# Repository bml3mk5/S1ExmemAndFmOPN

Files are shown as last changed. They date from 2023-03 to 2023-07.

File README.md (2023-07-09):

# Extended RAM & FM Synthesis Card for HITACHI MB-S1

This is the extension card for HITACHI MB-S1 and Limelight. This is assembled two circuits
which are extended RAMs and FM Synthesis (YAMAHA YM2203(OPN)). You can use two circuits, or just one of them.

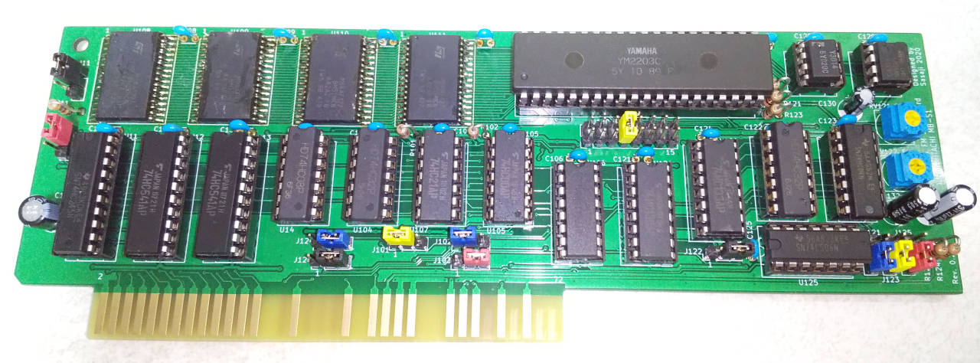
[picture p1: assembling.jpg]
Example of an assembling


## Used Tools

* KiCAD Version 5

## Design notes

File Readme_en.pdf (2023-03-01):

## Extended RAM & FM Synthesis Card for HITACHI MB-S1

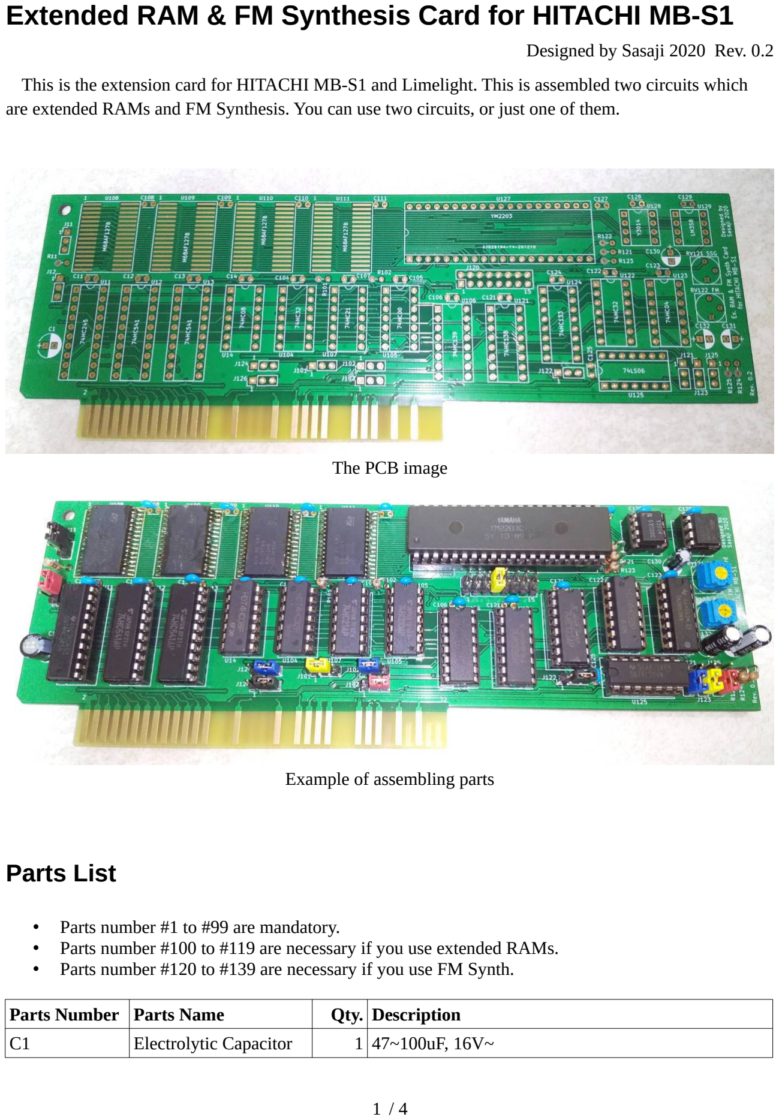
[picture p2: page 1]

Designed by Sasaji 2020 Rev. 0.2 This is the extension card for HITACHI MB-S1 and Limelight. This is assembled two circuits which are extended RAMs and FM Synthesis. You can use two circuits, or just one of them.

The PCB image

Example of assembling parts

## Parts List

- Parts number #1 to #99 are mandatory.
- Parts number #100 to #119 are necessary if you use extended RAMs.
- Parts number #120 to #139 are necessary if you use FM Synth.
Parts Number | Parts Name | Qty. | Description
C1 | Electrolytic Capacitor | 1 | 47~100uF, 16V~

C11~C129 | Ceramic Capacitor | 20 | 0.1uF
C130 | Electrolytic Capacitor | 1 | 10uF, 16V~
C131,C132 | Electrolytic Capacitor | 2 | 22uF~47uF, 16V~
R11~R102 | Carbon Resistor | 3 | 4.7KΩ~10KΩ, 1/4W~
R121~R125 | Carbon Resistor | 5 | 1KΩ, 1/4W～
RV121 | Potentiometer | 1 | 2KΩ Ex: Tokyo Cosmos GF063P1B202
RV122 | Potentiometer | 1 | 10KΩ Ex: Tokyo Cosmos GF063P1B103
U11 | CMOS Logic IC | 1 | 74HC245, DIP20
U12, U13 | CMOS Logic IC | 2 | 74HC541, DIP20
U14 | CMOS Logic IC | 1 | 74HC08, DIP14
U104,U122 | CMOS Logic IC | 2 | 74HC32, DIP14
U105 | CMOS Logic IC | 1 | 74HC00, DIP14
U106 | CMOS Logic IC | 1 | 74HC139, DIP16
U107 | CMOS Logic IC | 1 | 74HC21, DIP14
U108~U111 | SRAM | 4 | STMicro M68AF127B or compatible SRAM(618128), SOIC32
U121 | CMOS Logic IC | 1 | 74HC138, DIP16
U123 | CMOS Logic IC | 1 | 74HC04, DIP14
U124 | CMOS Logic IC | 1 | 74HC133, DIP16
U125 | TTLLogic IC | 1 | 74LS06, DIP14
U127 | FM Synth IC | 1 | YM2203, DIP40
U128 | DAC | 1 | Y3014, DIP8
U129 | Opamp | 1 | LM358 or LM2904, DIP8
J11~J126 | Jumper | 11 | Pin Header 3pin x1 2.54mm pitch
J120 | Jumper | 1 | Pin Header 8pin x2 2.54mm pitch
| Jumper pin | 12 | To short pin headers.
| ICsocket | | If need.

## Setting Jumper

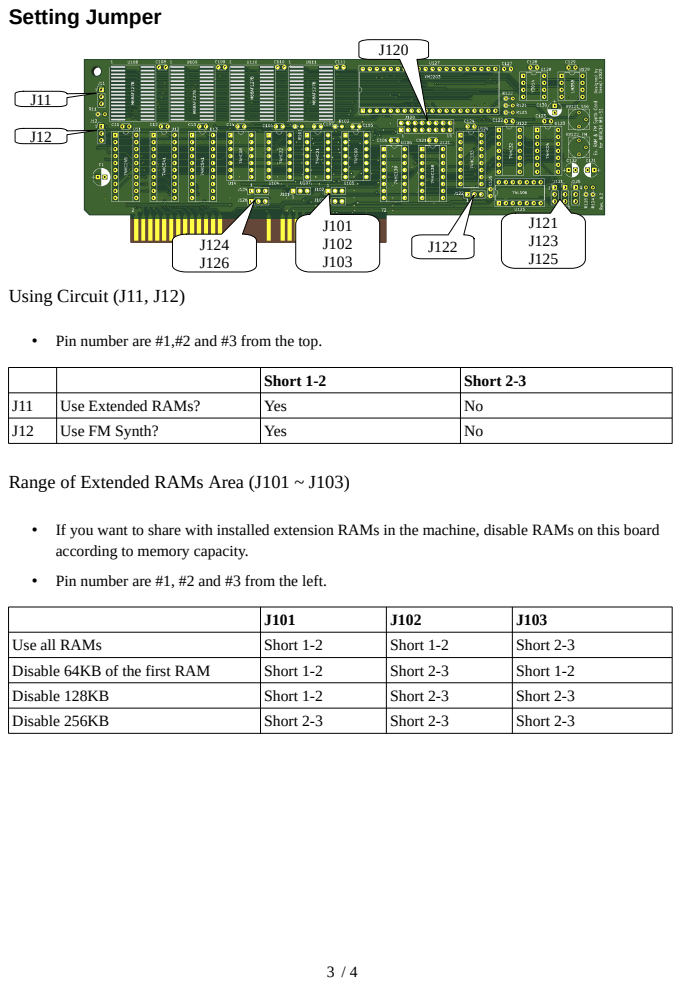
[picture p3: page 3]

• Pin number are #1,#2 and #3 from the top.

Short 1-2 | Short 2-3

J11 | Use Extended RAMs? | Yes | No
J12 | Use FM Synth? | Yes | No

Range of Extended RAMs Area (J101 ~ J103)

• If you want to share with installed extension RAMs in the machine, disable RAMs on this board
according to memory capacity.
• Pin number are #1, #2 and #3 from the left.

Use all RAMs | Short 1-2 | Short 1-2 | Short 2-3
Disable 64KB of the first RAM | Short 1-2 | Short 2-3 | Short 1-2
Disable 128KB | Short 1-2 | Short 2-3 | Short 2-3
Disable 256KB | Short 2-3 | Short 2-3 | Short 2-3

I/O Addresses of FM Synth (J120 ~ J125)

- Pin number #1 of J120 is the bottom left, #2 is the top left, and #16 is the top right. Short top pins and bottom pins.
- Pin number of J121, J123 and J125 are #1, #2 and #3 from the top.
- Pin number of J122 and J124 are #1, #2 and #3 from the left.
| J120 | J121 ~ J125
Use I/O Addresses at $FF1E and $FF1F | Short 15-16 | Short 1-2
Use I/O Addresses at $FFE6 and $FFE7 (*1) | Short 7-8 | Short 2-3

(*1) Select this if you use as Extended PSG.

Connecting Interrupt Signal of FM Synth (J126)

- Pin number are #1, #2 and #3 from the left.
| | Short 1-2 | Short 2-3
J126 | Connect to | IRQ | FIRQ

## Attention

- Make sure to short the jumper J120 only in one place. If you short-circuit multiple places, the IC will be destroyed.
- This board is a prototype. No consideration is given to noise generated during use and deterioration over time.

## Disclaimer

I am not responsible for any damage caused by this board. You use this board at your own risk.

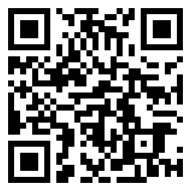
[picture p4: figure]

## Web

http://s-sasaji.ddo.jp/bml3mk5/s1exmemfm.htm QR Code --->

Sasaji (sasaji@s-sasaji.ddo.jp) http://s-sasaji.ddo.jp/bml3mk5/
(Twitter: https://twitter.com/bml3mk5)

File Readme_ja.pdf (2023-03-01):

## 拡張 RAM & FM 音源カード for 日立 MB-S1

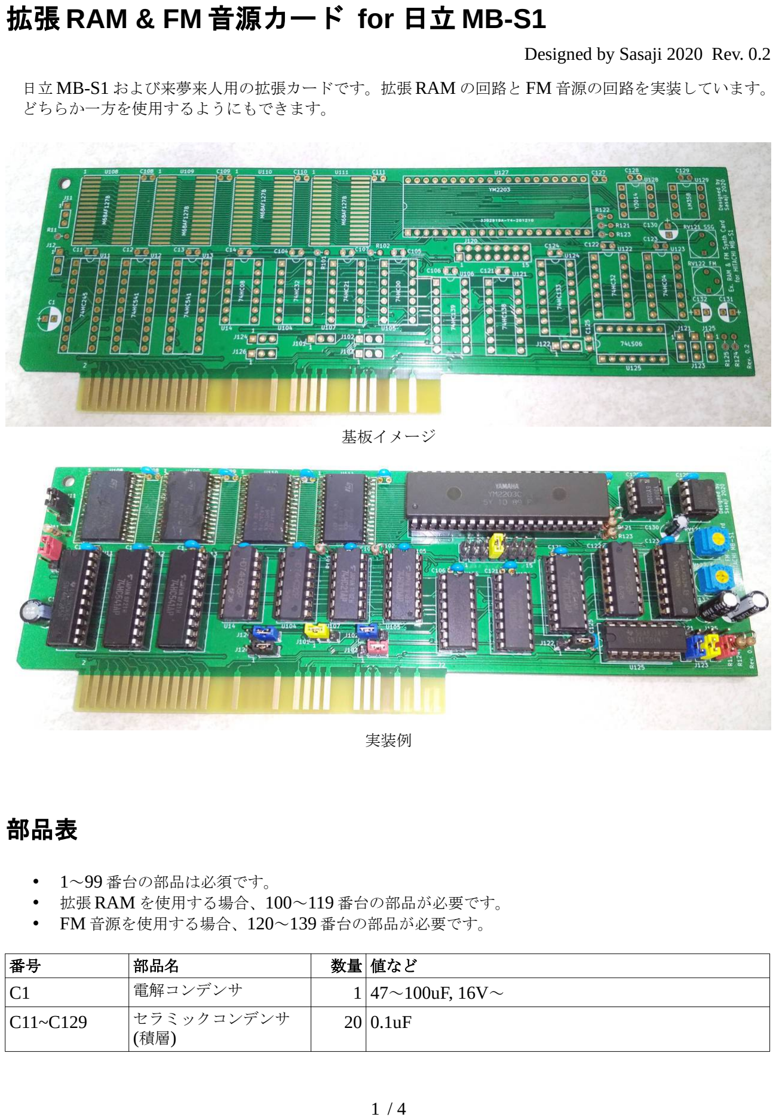
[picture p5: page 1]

Designed by Sasaji 2020 Rev. 0.2

日立 MB-S1 および来夢来人用の拡張カードです。拡張 RAM の回路と FM 音源の回路を実装しています。 どちらか一方を使用するようにもできます。

基板イメージ

実装例

### 部品表

- 1～99 番台の部品は必須です。
- 拡張 RAM を使用する場合、100～119 番台の部品が必要です。
- FM 音源を使用する場合、120～139 番台の部品が必要です。
番号 | 部品名 | 数量 | 値など
C1 | 電解コンデンサ | 1 | 47～100uF, 16V～
C11~C129 | セラミックコンデンサ (積層) | 20 | 0.1uF

C130 | 電解コンデンサ | 1 | 10uF, 16V～
C131,C132 | 電解コンデンサ | 2 | 22uF～47uF, 16V～
R11~R102 | カーボン抵抗 | 3 | 4.7KΩ～10KΩ, 1/4W～
R121~R125 | カーボン抵抗 | 5 | 1KΩ, 1/4W～
RV121 | 半固定抵抗(ポテンショ メータ) | 1 | 2KΩ 東京コスモス電機 GF063P1B202 など
RV122 | 半固定抵抗(ポテンショ メータ) | 1 | 10KΩ 東京コスモス電機 GF063P1B103 など
U11 | CMOS ロジック IC | 1 | 74HC245, DIP20 ピン
U12, U13 | CMOS ロジック IC | 2 | 74HC541, DIP20 ピン
U14 | CMOS ロジック IC | 1 | 74HC08, DIP14 ピン
U104,U122 | CMOS ロジック IC | 2 | 74HC32, DIP14 ピン
U105 | CMOS ロジック IC | 1 | 74HC00, DIP14 ピン
U106 | CMOS ロジック IC | 1 | 74HC139, DIP16 ピン
U107 | CMOS ロジック IC | 1 | 74HC21, DIP14 ピン
U108~U111 | SRAM | 4 | M68AF127B または互換 SRAM(618128), SOIC32 ピ ン
U121 | CMOS ロジック IC | 1 | 74HC138, DIP16 ピン
U123 | CMOS ロジック IC | 1 | 74HC04, DIP14 ピン
U124 | CMOS ロジック IC | 1 | 74HC133, DIP16 ピン
U125 | TTL ロジック IC | 1 | 74LS06, DIP14 ピン
U127 | FM 音源 IC | 1 | YM2203, DIP40 ピン
U128 | DAC | 1 | Y3014, DIP8 ピン
U129 | オペアンプ | 1 | LM358 や LM2904 など単電源のもの, DIP8 ピン
J11~J126 | ジャンパ | 11 | ピンヘッダ 3 ピン x1 列 2.54mm ピッチ
J120 | ジャンパ | 1 | ピンヘッダ 8 ピン x2 列 2.54mm ピッチ
| ジャンパピン | 12 | 上記ピンヘッダをショートさせるため
| IC ソケット | | FM 音源は貴重なのでソケットを介したほうがいいか も。

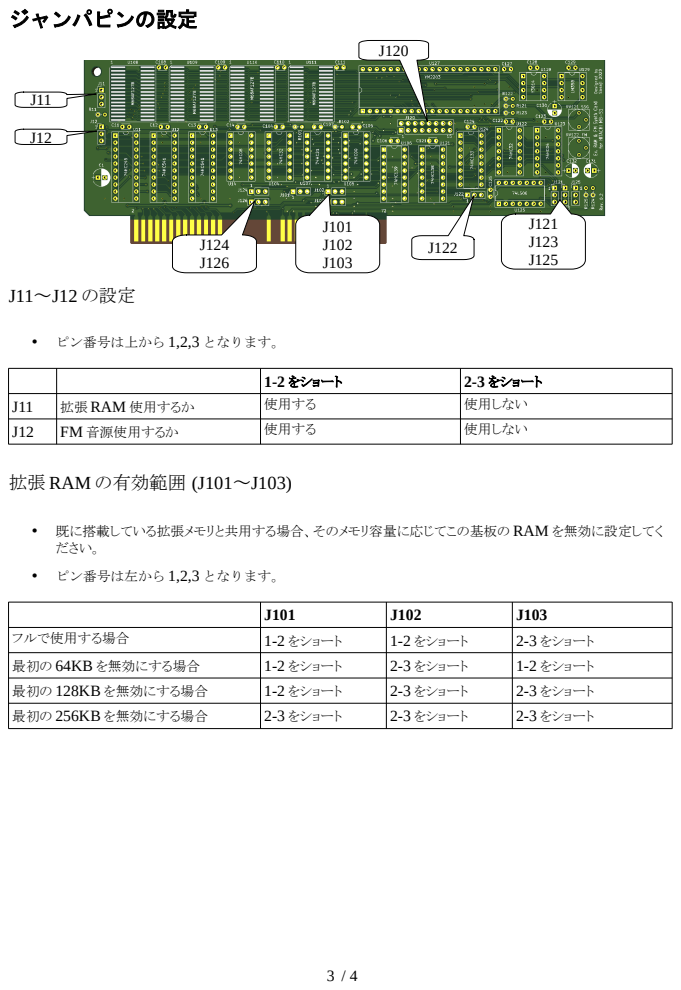
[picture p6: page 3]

1-2 をショート | 2-3 をショート

J11 | 拡張 RAM 使用するか | 使用する | 使用しない
J12 | FM 音源使用するか | 使用する | 使用しない

• 既に搭載している拡張メモリと共用する場合、そのメモリ容量に応じてこの基板の RAM を無効に設定してく
ださい。
• ピン番号は左から 1,2,3 となります。

フルで使用する場合 | 1-2 をショート | 1-2 をショート | 2-3 をショート
最初の 64KB を無効にする場合 | 1-2 をショート | 2-3 をショート | 1-2 をショート
最初の 128KB を無効にする場合 | 1-2 をショート | 2-3 をショート | 2-3 をショート
最初の 256KB を無効にする場合 | 2-3 をショート | 2-3 をショート | 2-3 をショート

FM 音源の I/O アドレス (J120～J125)

- J120 のピン番号は下が左から 1,3,5,...奇数、上が左から 2,4,6,...偶数となります。上と下をショート させます。
- J121,J123,J125 のピン番号は上から 1,2,3 となります。
- J122,J124 のピン番号は左から 1,2,3 となります。
| J120 | J121～J125
I/O アドレス $FF1E, $FF1F で使用する場合 | 15-16 をショート | 1-2 をショート
I/O アドレス $FFE6, $FFE7 で使用する場合(*1) | 7-8 をショート | 2-3 をショート

(*1)拡張 PSG として使用する場合はこちらを選択してください。

FM 音源の割り込み信号接続先(J126)

- ピン番号は左から 1,2,3 となります。
| | 1-2 をショート | 2-3 をショート
J126 | 割り込み信号接続先 | IRQ | FIRQ

### 使用上の注意

- ジャンパ J120 は一箇所のみショートさせるようにしてください。複数箇所ショートさせると IC が破 壊されます。
- この基板は試作品です。使用中に発生するノイズや経年劣化などに対しての考慮は全くしていません ので予めご了承ください。

### 免責事項

この基板によって発生したいかなる損害についても当方は一切責任を負いません。 この基板を使用するにあたってはすべて自己責任で行ってください。


## Web ページ

http://s-sasaji.ddo.jp/bml3mk5/s1exmemfm.htm
QR コード→

連絡先：
Sasaji (sasaji@s-sasaji.ddo.jp) http://s-sasaji.ddo.jp/bml3mk5/(Twitter: https://twitter.com/bml3mk5)

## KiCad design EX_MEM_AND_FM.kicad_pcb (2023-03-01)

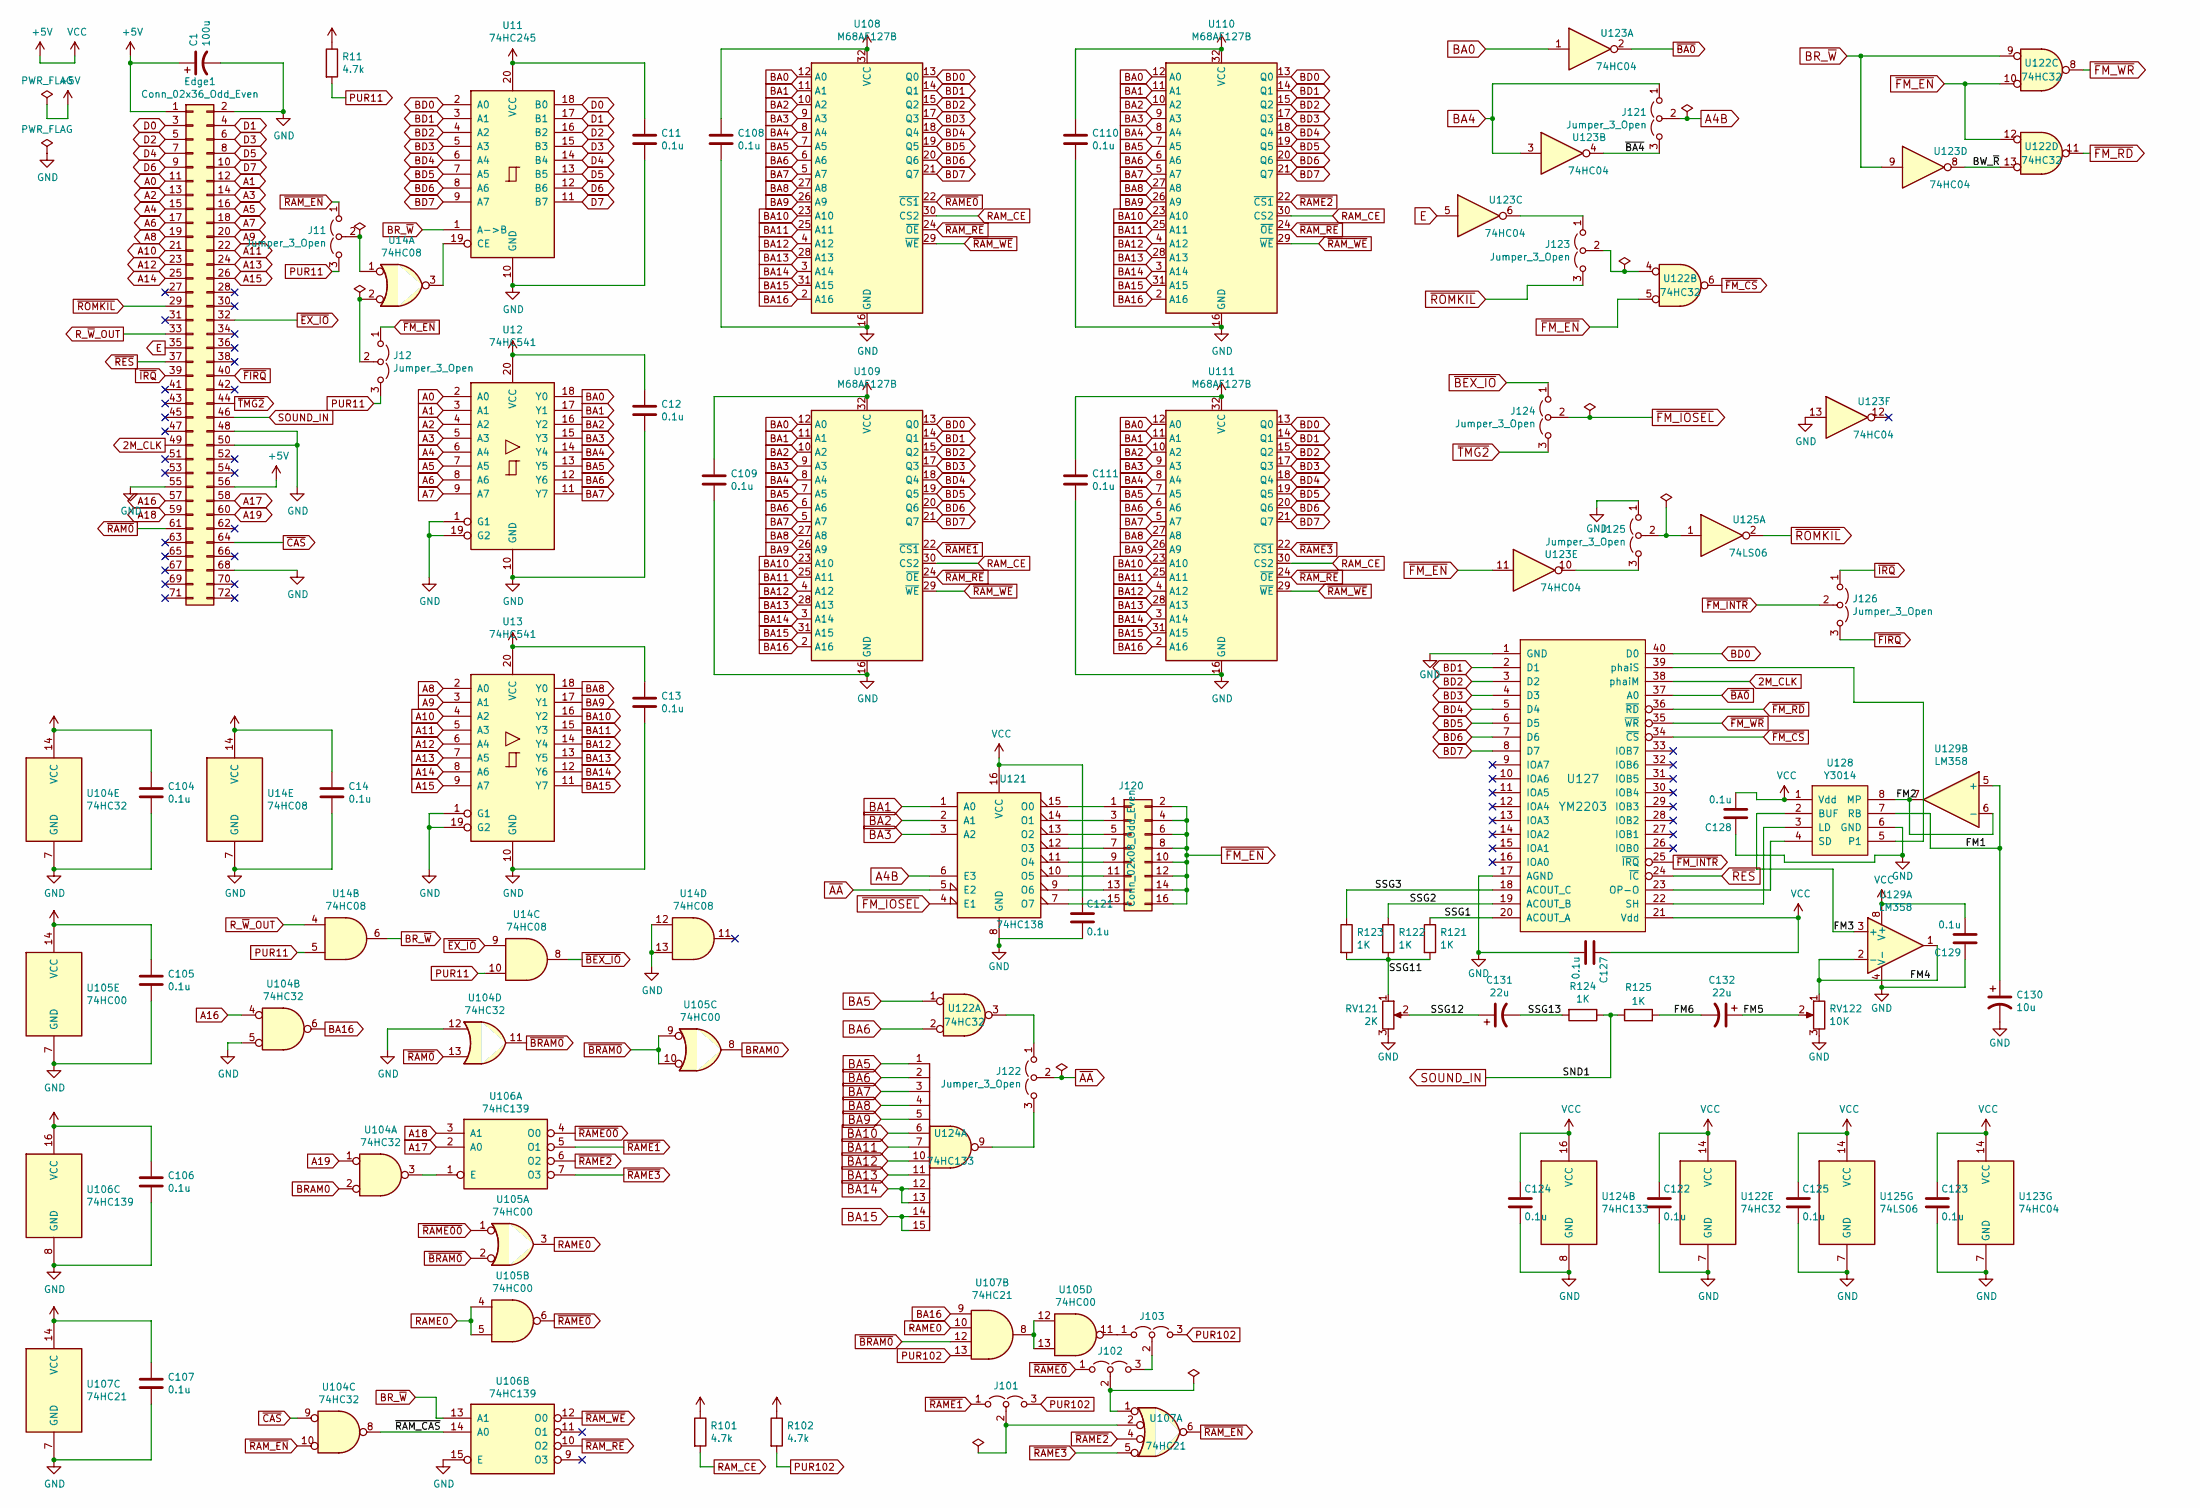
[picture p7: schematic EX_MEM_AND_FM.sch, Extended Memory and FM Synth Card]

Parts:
C1: 100u; CP_Radial_D6.3mm_P2.50mm
C11, C12, C13, C14, C104, C105, C106, C107, C108, C109, C110, C111, C121, C122, C123, C124, C125, C127, C128, C129: 0.1u; C_Disc_D3.0mm_W2.0mm_P2.50mm
C130: 10u; CP_Radial_D5.0mm_P2.50mm
C131, C132: 22u; CP_Radial_D5.0mm_P2.50mm
Edge1: Conn_02x36_Odd_Even; CardEdge72
J11, J12, J101, J102, J103, J121, J122, J123, J124, J125, J126: Jumper_3_Open; Pin_Header_Straight_1x03_Pitch2.54mm
J120: Conn_02x08_Odd_Even; Pin_Header_Straight_2x08_Pitch2.54mm
R11, R101, R102: 4.7k; R_Axial_DIN0204_L3.6mm_D1.6mm_P2.54mm_Vertical
R121, R122, R123, R124, R125: 1K; R_Axial_DIN0204_L3.6mm_D1.6mm_P2.54mm_Vertical
RV121: 2K; Potentiometer_Trimmer_Bourns_3339P_Horizontal
RV122: 10K; Potentiometer_Trimmer_Bourns_3339P_Horizontal
U11: 74HC245; DIP-20_W7.62mm
U12, U13: 74HC541; DIP-20_W7.62mm
U14: 74HC08; DIP-14_W7.62mm
U104, U122: 74HC32; DIP-14_W7.62mm
U105: 74HC00; DIP-14_W7.62mm
U106: 74HC139; DIP-16_W7.62mm
U107: 74HC21; DIP-14_W7.62mm
U108, U109, U110, U111: M68AF127B; SOIC-32
U121: 74HC138; DIP-16_W7.62mm
U123: 74HC04; DIP-14_W7.62mm
U124: 74HC133; DIP-16_W7.62mm
U125: 74LS06; DIP-14_W7.62mm
U127: YM2203; DIP-40_W15.24mm_Socket
U128: Y3014; DIP-8_W7.62mm_Socket
U129: LM358; DIP-8_W7.62mm_Socket

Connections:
2M_CLK: Edge1.49, U127.38 (phaiM)
+5V: C1.1, C11.1, C12.1, C13.1, C14.1, C104.1, C105.1, C106.1, C107.1, C108.1, C109.1, C110.1, C111.1, C121.1, C122.1, C123.1, C124.1, C125.1, C127.1, C128.2, C129.2, Edge1.1, Edge1.56, R11.1, R101.1, R102.1, U11.20 (VCC), U12.20 (VCC), U13.20 (VCC), U14.14 (VCC), U104.14 (VCC), U105.14 (VCC), U106.16 (VCC), U107.14 (VCC), U108.32 (VCC), U109.32 (VCC), U110.32 (VCC), U111.32 (VCC), U121.16 (VCC), U122.14 (VCC), U123.14 (VCC), U124.16 (VCC), U125.14 (VCC), U127.21 (Vdd), U128.1 (Vdd), U129.8 (V+)
/BW_~R~: U122.13, U123.8
/FM1: C130.1, U128.7 (RB), U129.5 (+)
/FM2: U128.8 (MP), U129.6 (-), U129.7
/FM3: U128.2 (BUF), U129.3 (+)
/FM4: RV122.1, U129.1, U129.2 (-)
/FM5: C132.1, RV122.2
/FM6: C132.2, R125.2
/SSG1: R121.1, U127.20 (ACOUT_A)
/SSG2: R122.1, U127.19 (ACOUT_B)
/SSG3: R123.1, U127.18 (ACOUT_C)
/SSG11: R121.2, R122.2, R123.2, RV121.1
/SSG12: C131.1, RV121.2
/SSG13: C131.2, R124.2
/~BA4: J121.3 (B), U123.4
/~RAM_CAS: U104.8, U106.14 (A0)
A0: Edge1.11, U12.2 (A0)
A1: Edge1.12, U12.3 (A1)
A2: Edge1.13, U12.4 (A2)
A3: Edge1.14, U12.5 (A3)
A4: Edge1.15, U12.6 (A4)
A4B: J121.2 (C), U121.6 (E3)
A5: Edge1.16, U12.7 (A5)
A6: Edge1.17, U12.8 (A6)
A7: Edge1.18, U12.9 (A7)
A8: Edge1.19, U13.2 (A0)
A9: Edge1.20, U13.3 (A1)
A10: Edge1.21, U13.4 (A2)
A11: Edge1.22, U13.5 (A3)
A12: Edge1.23, U13.6 (A4)
A13: Edge1.24, U13.7 (A5)
A14: Edge1.25, U13.8 (A6)
A15: Edge1.26, U13.9 (A7)
A16: Edge1.57, U104.4
A17: Edge1.58, U106.2 (A0)
A18: Edge1.59, U106.3 (A1)
A19: Edge1.60, U104.1
BA0: U12.18 (Y0), U108.12 (A0), U109.12 (A0), U110.12 (A0), U111.12 (A0), U123.1
BA1: U12.17 (Y1), U108.11 (A1), U109.11 (A1), U110.11 (A1), U111.11 (A1), U121.1 (A0)
BA2: U12.16 (Y2), U108.10 (A2), U109.10 (A2), U110.10 (A2), U111.10 (A2), U121.2 (A1)
BA3: U12.15 (Y3), U108.9 (A3), U109.9 (A3), U110.9 (A3), U111.9 (A3), U121.3 (A2)
BA4: J121.1 (A), U12.14 (Y4), U108.8 (A4), U109.8 (A4), U110.8 (A4), U111.8 (A4), U123.3
BA5: U12.13 (Y5), U108.7 (A5), U109.7 (A5), U110.7 (A5), U111.7 (A5), U122.1, U124.1
BA6: U12.12 (Y6), U108.6 (A6), U109.6 (A6), U110.6 (A6), U111.6 (A6), U122.2, U124.2
BA7: U12.11 (Y7), U108.5 (A7), U109.5 (A7), U110.5 (A7), U111.5 (A7), U124.3
BA8: U13.18 (Y0), U108.27 (A8), U109.27 (A8), U110.27 (A8), U111.27 (A8), U124.4
BA9: U13.17 (Y1), U108.26 (A9), U109.26 (A9), U110.26 (A9), U111.26 (A9), U124.5
BA10: U13.16 (Y2), U108.23 (A10), U109.23 (A10), U110.23 (A10), U111.23 (A10), U124.6
BA11: U13.15 (Y3), U108.25 (A11), U109.25 (A11), U110.25 (A11), U111.25 (A11), U124.7
BA12: U13.14 (Y4), U108.4 (A12), U109.4 (A12), U110.4 (A12), U111.4 (A12), U124.10
BA13: U13.13 (Y5), U108.28 (A13), U109.28 (A13), U110.28 (A13), U111.28 (A13), U124.11
BA14: U13.12 (Y6), U108.3 (A14), U109.3 (A14), U110.3 (A14), U111.3 (A14), U124.12, U124.13
BA15: U13.11 (Y7), U108.31 (A15), U109.31 (A15), U110.31 (A15), U111.31 (A15), U124.14, U124.15
BA16: U104.6, U107.9, U108.2 (A16), U109.2 (A16), U110.2 (A16), U111.2 (A16)
BD0: U11.2 (A0), U108.13 (Q0), U109.13 (Q0), U110.13 (Q0), U111.13 (Q0), U127.40 (D0)
BD1: U11.3 (A1), U108.14 (Q1), U109.14 (Q1), U110.14 (Q1), U111.14 (Q1), U127.2 (D1)
BD2: U11.4 (A2), U108.15 (Q2), U109.15 (Q2), U110.15 (Q2), U111.15 (Q2), U127.3 (D2)
BD3: U11.5 (A3), U108.17 (Q3), U109.17 (Q3), U110.17 (Q3), U111.17 (Q3), U127.4 (D3)
BD4: U11.6 (A4), U108.18 (Q4), U109.18 (Q4), U110.18 (Q4), U111.18 (Q4), U127.5 (D4)
BD5: U11.7 (A5), U108.19 (Q5), U109.19 (Q5), U110.19 (Q5), U111.19 (Q5), U127.6 (D5)
BD6: U11.8 (A6), U108.20 (Q6), U109.20 (Q6), U110.20 (Q6), U111.20 (Q6), U127.7 (D6)
BD7: U11.9 (A7), U108.21 (Q7), U109.21 (Q7), U110.21 (Q7), U111.21 (Q7), U127.8 (D7)
BRAM0: U104.2, U105.8
BR_~W: U11.1 (A->B), U14.6, U106.13 (A1), U122.9, U123.9
D0: Edge1.3, U11.18 (B0)
D1: Edge1.4, U11.17 (B1)
D2: Edge1.5, U11.16 (B2)
D3: Edge1.6, U11.15 (B3)
D4: Edge1.7, U11.14 (B4)
D5: Edge1.8, U11.13 (B5)
D6: Edge1.9, U11.12 (B6)
D7: Edge1.10, U11.11 (B7)
E: Edge1.35, U123.5
GND: C1.2, C11.2, C12.2, C13.2, C14.2, C104.2, C105.2, C106.2, C107.2, C108.2, C109.2, C110.2, C111.2, C121.2, C122.2, C123.2, C124.2, C125.2, C127.2, C128.1, C129.1, C130.2, Edge1.2, Edge1.48, Edge1.50, Edge1.55, Edge1.68, J125.1 (A), RV121.3, RV122.3, U11.10 (GND), U12.1 (G1), U12.10 (GND), U12.19 (G2), U13.1 (G1), U13.10 (GND), U13.19 (G2), U14.7 (GND), U14.12, U14.13, U104.5, U104.7 (GND), U104.12, U105.7 (GND), U106.8 (GND), U106.15 (E), U107.7 (GND), U108.16 (GND), U109.16 (GND), U110.16 (GND), U111.16 (GND), U121.8 (GND), U122.7 (GND), U123.7 (GND), U123.13, U124.8 (GND), U125.7 (GND), U127.1 (GND), U127.17 (AGND), U128.6 (GND), U129.4 (V-)
unnamed: J11.2 (C), U14.1
unnamed: J12.2 (C), U14.2
unnamed: J101.2 (C), U107.2
unnamed: J102.2 (C), U107.1
unnamed: J102.3 (B), J103.2 (C)
unnamed: J103.1 (A), U105.11
unnamed: J120.1, U121.15 (O0)
unnamed: J120.3, U121.14 (O1)
unnamed: J120.5, U121.13 (O2)
unnamed: J120.7, U121.12 (O3)
unnamed: J120.9, U121.11 (O4)
unnamed: J120.11, U121.10 (O5)
unnamed: J120.13, U121.9 (O6)
unnamed: J120.15, U121.7 (O7)
unnamed: J122.1 (A), U122.3
unnamed: J122.3 (B), U124.9
unnamed: J123.1 (A), U123.6
unnamed: J123.2 (C), U122.4
unnamed: J125.2 (C), U125.1
unnamed: J125.3 (B), U123.10
unnamed: U11.19 (CE), U14.3
unnamed: U104.3, U106.1 (E)
unnamed: U105.12, U105.13, U107.8
unnamed: U127.22 (SH), U128.3 (LD)
unnamed: U127.23 (OP-O), U128.4 (SD)
unnamed: U127.39 (phaiS), U128.5 (P1)
PUR11: J11.3 (B), J12.3 (B), R11.2, U14.5, U14.10
PUR102: J101.3 (B), J103.3 (B), R102.2, U107.13
RAME0: U105.3, U105.4, U105.5, U107.10
RAM_CE: R101.2, U108.30 (CS2), U109.30 (CS2), U110.30 (CS2), U111.30 (CS2)
R_~W~_OUT: Edge1.33, U14.4
SOUND_IN: Edge1.46, R124.1, R125.1
~AA: J122.2 (C), U121.5 (E2)
~BA0: U123.2, U127.37 (A0)
~BEX_IO: J124.1 (A), U14.8
~BRAM0: U104.11, U105.2, U105.9, U105.10, U107.12
~CAS: Edge1.64, U104.9
~EX_IO: Edge1.32, U14.9
~FIRQ: Edge1.40, J126.3 (B)
~FM_CS: U122.6, U127.34 (~CS)
~FM_EN: J12.1 (A), J120.2, J120.4, J120.6, J120.8, J120.10, J120.12, J120.14, J120.16, U122.5, U122.10, U122.12, U123.11
~FM_INTR: J126.2 (C), U127.25 (~IRQ)
~FM_IOSEL: J124.2 (C), U121.4 (E1)
~FM_RD: U122.11, U127.36 (~RD)
~FM_WR: U122.8, U127.35 (~WR)
~IRQ: Edge1.39, J126.1 (A)
~RAM0: Edge1.61, U104.13
~RAME00: U105.1, U106.4 (O0)
~RAME0: J102.1 (A), U105.6, U108.22 (~CS1)
~RAME1: J101.1 (A), U106.5 (O1), U109.22 (~CS1)
~RAME2: U106.6 (O2), U107.4, U110.22 (~CS1)
~RAME3: U106.7 (O3), U107.5, U111.22 (~CS1)
~RAM_EN: J11.1 (A), U104.10, U107.6
~RAM_RE: U106.10 (O2), U108.24 (~OE), U109.24 (~OE), U110.24 (~OE), U111.24 (~OE)
~RAM_WE: U106.12 (O0), U108.29 (~WE), U109.29 (~WE), U110.29 (~WE), U111.29 (~WE)
~RES: Edge1.37, U127.24 (~IC)
~ROMKIL: Edge1.29, J123.3 (B), U125.2
~TMG2: Edge1.44, J124.3 (B)

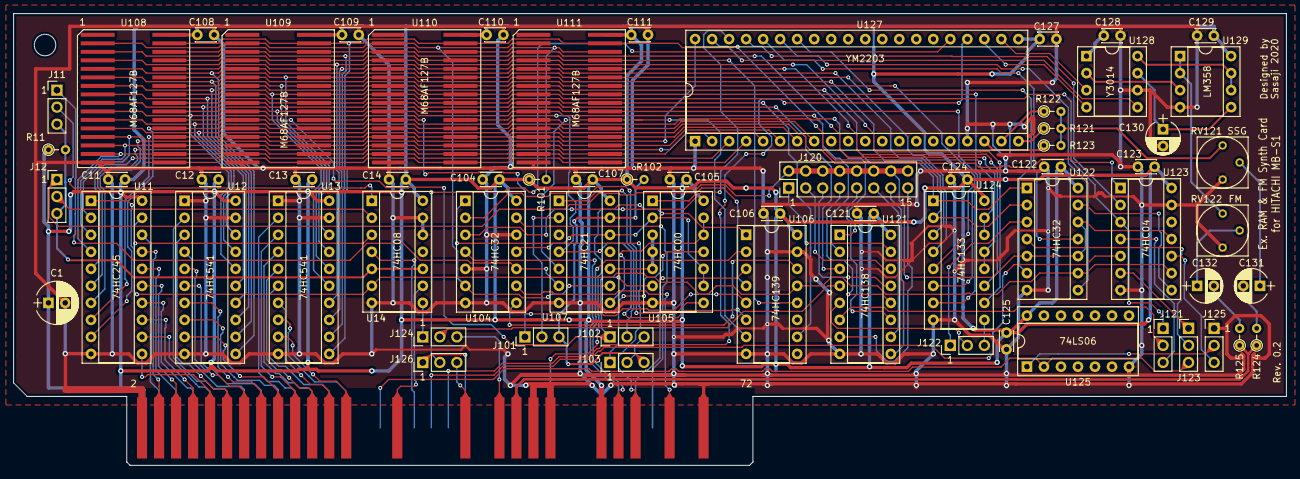
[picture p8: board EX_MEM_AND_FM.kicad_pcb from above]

Board: 2 copper layers, 190.0 x 67.4 mm, 67 parts (0 on the bottom side), 133 nets.
